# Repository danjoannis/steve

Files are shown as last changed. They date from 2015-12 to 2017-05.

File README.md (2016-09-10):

# steve
Self-Training Electronic Vehicle for Exploration

STEVE is a fun little hobby project, combining an RC tank platform with a Raspberry Pi, Arduino Mega,
and plenty of sensors to allow him to discover the world.

The longterm goal is a robot which can autonomously navigate through environments in order to
reach assigned targets.

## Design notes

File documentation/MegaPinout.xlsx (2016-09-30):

Pin Number | Pin Name | Mapped Pin Name | Peripheral | Function
1 | PG5 ( OC0B ) | Digital pin 4 (PWM)
2 | PE0 ( RXD0/PCINT8 ) | Digital pin 0 (RX0)
3 | PE1 ( TXD0 ) | Digital pin 1 (TX0)
4 | PE2 ( XCK0/AIN0 )
5 | PE3 ( OC3A/AIN1 ) | Digital pin 5 (PWM)
6 | PE4 ( OC3B/INT4 ) | Digital pin 2 (PWM) | MOTOR | EN_A
7 | PE5 ( OC3C/INT5 ) | Digital pin 3 (PWM) | MOTOR | EN_B
8 | PE6 ( T3/INT6 )
9 | PE7 ( CLKO/ICP3/INT7 )
10 | VCC | VCC
11 | GND | GND
12 | PH0 ( RXD2 ) | Digital pin 17 (RX2)
13 | PH1 ( TXD2 ) | Digital pin 16 (TX2)
14 | PH2 ( XCK2 )
15 | PH3 ( OC4A ) | Digital pin 6 (PWM)
16 | PH4 ( OC4B ) | Digital pin 7 (PWM)
17 | PH5 ( OC4C ) | Digital pin 8 (PWM)
18 | PH6 ( OC2B ) | Digital pin 9 (PWM)
19 | PB0 ( SS/PCINT0 ) | Digital pin 53 (SS)
20 | PB1 ( SCK/PCINT1 ) | Digital pin 52 (SCK)
21 | PB2 ( MOSI/PCINT2 ) | Digital pin 51 (MOSI)
22 | PB3 ( MISO/PCINT3 ) | Digital pin 50 (MISO)
23 | PB4 ( OC2A/PCINT4 ) | Digital pin 10 (PWM)
24 | PB5 ( OC1A/PCINT5 ) | Digital pin 11 (PWM)
25 | PB6 ( OC1B/PCINT6 ) | Digital pin 12 (PWM)
26 | PB7 ( OC0A/OC1C/PCINT7 ) | Digital pin 13 (PWM)
27 | PH7 ( T4 )
28 | PG3 ( TOSC2 )
29 | PG4 ( TOSC1 )
30 | RESET | RESET
31 | VCC | VCC
32 | GND | GND
33 | XTAL2 | XTAL2
34 | XTAL1 | XTAL1
35 | PL0 ( ICP4 ) | Digital pin 49
36 | PL1 ( ICP5 ) | Digital pin 48
37 | PL2 ( T5 ) | Digital pin 47
38 | PL3 ( OC5A ) | Digital pin 46 (PWM)
39 | PL4 ( OC5B ) | Digital pin 45 (PWM)
40 | PL5 ( OC5C ) | Digital pin 44 (PWM)
41 | PL6 | Digital pin 43 | SONAR_FRONT | TRIG
42 | PL7 | Digital pin 42 | SONAR_FRONT | ECHO
43 | PD0 ( SCL/INT0 ) | Digital pin 21 (SCL)
44 | PD1 ( SDA/INT1 ) | Digital pin 20 (SDA)
45 | PD2 ( RXDI/INT2 ) | Digital pin 19 (RX1)
46 | PD3 ( TXD1/INT3 ) | Digital pin 18 (TX1)
47 | PD4 ( ICP1 )
48 | PD5 ( XCK1 )
49 | PD6 ( T1 )
50 | PD7 ( T0 ) | Digital pin 38
51 | PG0 ( WR ) | Digital pin 41
52 | PG1 ( RD ) | Digital pin 40
53 | PC0 ( A8 ) | Digital pin 37 | PWR BOARD | MOTOR_EN
54 | PC1 ( A9 ) | Digital pin 36 | PWR BOARD | PI_EN
55 | PC2 ( A10 ) | Digital pin 35
56 | PC3 ( A11 ) | Digital pin 34 | MOTOR | IN_4
57 | PC4 ( A12 ) | Digital pin 33 | MOTOR | IN_3
58 | PC5 ( A13 ) | Digital pin 32 | MOTOR | IN_2
59 | PC6 ( A14 ) | Digital pin 31 | MOTOR | IN_1
60 | PC7 ( A15 ) | Digital pin 30
61 | VCC | VCC
62 | GND | GND
63 | PJ0 ( RXD3/PCINT9 ) | Digital pin 15 (RX3)
64 | PJ1 ( TXD3/PCINT10 ) | Digital pin 14 (TX3)
65 | PJ2 ( XCK3/PCINT11 )
66 | PJ3 ( PCINT12 )
67 | PJ4 ( PCINT13 )
68 | PJ5 ( PCINT14 )
69 | PJ6 ( PCINT 15 )
70 | PG2 ( ALE ) | Digital pin 39
71 | PA7 ( AD7 ) | Digital pin 29
72 | PA6 ( AD6 ) | Digital pin 28
73 | PA5 ( AD5 ) | Digital pin 27
74 | PA4 ( AD4 ) | Digital pin 26
75 | PA3 ( AD3 ) | Digital pin 25
76 | PA2 ( AD2 ) | Digital pin 24
77 | PA1 ( AD1 ) | Digital pin 23
78 | PA0 ( AD0 ) | Digital pin 22
79 | PJ7
80 | VCC | VCC
81 | GND | GND
82 | PK7 ( ADC15/PCINT23 ) | Analog pin 15
83 | PK6 ( ADC14/PCINT22 ) | Analog pin 14
84 | PK5 ( ADC13/PCINT21 ) | Analog pin 13
85 | PK4 ( ADC12/PCINT20 ) | Analog pin 12
86 | PK3 ( ADC11/PCINT19 ) | Analog pin 11
87 | PK2 ( ADC10/PCINT18 ) | Analog pin 10
88 | PK1 ( ADC9/PCINT17 ) | Analog pin 9
89 | PK0 ( ADC8/PCINT16 ) | Analog pin 8
90 | PF7 ( ADC7 ) | Analog pin 7
91 | PF6 ( ADC6 ) | Analog pin 6
92 | PF5 ( ADC5/TMS ) | Analog pin 5
93 | PF4 ( ADC4/TMK ) | Analog pin 4
94 | PF3 ( ADC3 ) | Analog pin 3
95 | PF2 ( ADC2 ) | Analog pin 2
96 | PF1 ( ADC1 ) | Analog pin 1
97 | PF0 ( ADC0 ) | Analog pin 0 | BATTERY | V_batt
98 | AREF | Analog Reference
99 | GND | GND
100 | AVCC | VCC

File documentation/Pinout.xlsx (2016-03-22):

Pin | Digital # | Type | PWM | Special | Assignment
A0 | 14 | Analog
A1 | 15 | Analog
A2 | 16 | Analog
A3 | 17 | Analog
A4 | 18 | Analog |  | SDA | IMU
A5 | 19 | Analog |  | SCL | IMU
PD0 | 0 | Digital |  | RX
PD1 | 1 | Digital |  | TX
PD2 | 2 | Digital |  | INT0
PD3 | 3 | Digital | YES | INT1
PD4 | 4 | Digital
PD5 | 5 | Digital | YES
PD6 | 6 | Digital | YES |  | TRIG
PD7 | 7 | Digital |  |  | ECHO
PB0 | 8 | Digital |  |  | B2
PB1 | 9 | Digital | YES |  | A2
PB2 | 10 | Digital | YES | SS | EN2
PB3 | 11 | Digital | YES | MOSI | EN1
PB4 | 12 | Digital |  | MISO | A1
PB6 | 13 | Digital |  | SCK | B1

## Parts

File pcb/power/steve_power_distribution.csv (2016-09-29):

Id | Designator | Package | Quantity | Designation | Supplier and ref
1 | D1,D2 | SMA_Handsoldering | 2 | D
2 | P1 | TerminalBlock_Pheonix_PT-3.5mm_2pol | 1 | BATT_1
3 | P2 | TerminalBlock_Pheonix_PT-3.5mm_2pol | 1 | BATT_2
4 | P3 | TerminalBlock_Pheonix_PT-3.5mm_2pol | 1 | BATT_3
5 | P4 | TerminalBlock_Pheonix_PT-3.5mm_2pol | 1 | BATT_4
6 | P6 | TerminalBlock_Pheonix_PT-3.5mm_2pol | 1 | MOTORS
7 | P7 | TerminalBlock_Pheonix_PT-3.5mm_2pol | 1 | 5V_PI
8 | P8 | TerminalBlock_Pheonix_PT-3.5mm_2pol | 1 | 5V_AVR
9 | Q1,Q2 | TO-252-2Lead | 2 | Q_NMOS_GDS
10 | R1 | Resistor_Horizontal_RM10mm | 1 | 33k
11 | R2,R5,R6 | Resistor_Horizontal_RM10mm | 3 | 15k
12 | R3,R4 | Resistor_Horizontal_RM10mm | 2 | 220
13 | U1 | LM2596S_CARRIER | 1 | LM2596S_Carrier
14 | P10 | Pin_Header_Straight_1x05 | 1 | AVR_INTERFACE
15 | P9 | TerminalBlock_Pheonix_PT-3.5mm_2pol | 1 | 5V_AUX
16 | P11,P12,P13,P14 | MOUNT_HOLE | 4 | MOUNT_HOLE
17 | P5 | TerminalBlock_Pheonix_PT-3.5mm_2pol | 1 | BATT_AUX

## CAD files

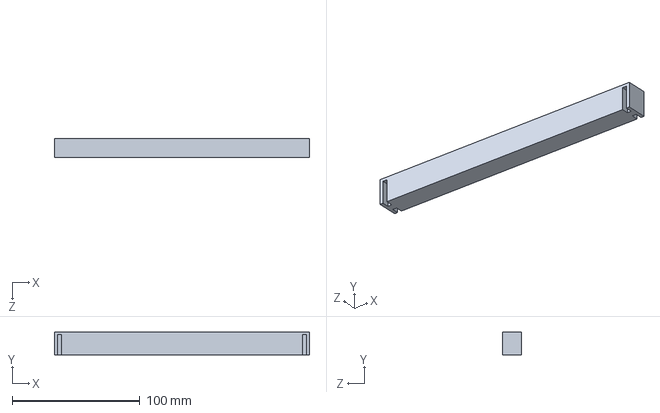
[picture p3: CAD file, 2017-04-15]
3D_Parts/Top_Transverse_Bar.SLDPRT
200.0 x 18.0 x 15.0 mm

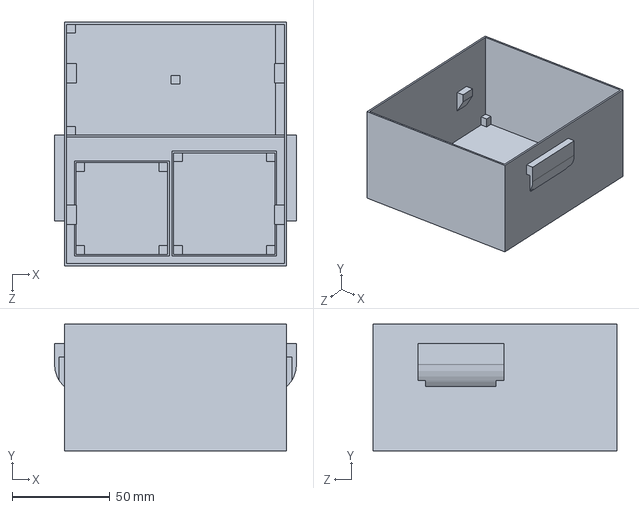
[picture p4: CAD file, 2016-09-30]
3D_Parts/Box_v2.SLDPRT
124.0 x 65.0 x 125.0 mm

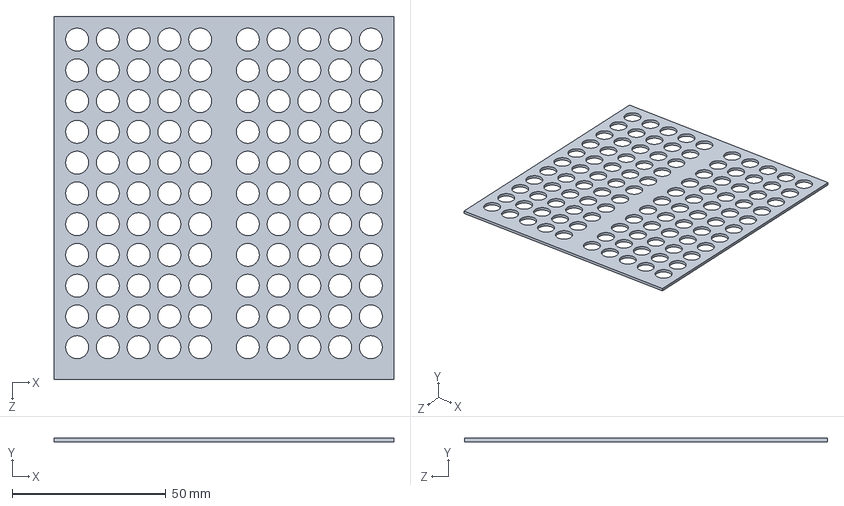
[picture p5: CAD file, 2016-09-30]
3D_Parts/Box_Grill.SLDPRT
110.5 x 1.20 x 118.0 mm

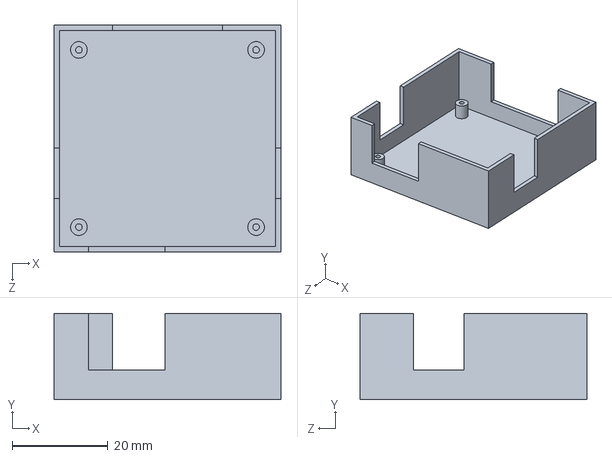
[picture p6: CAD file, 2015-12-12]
3D_Parts/LM298_Box.SLDPRT
47.4 x 18.0 x 47.4 mm

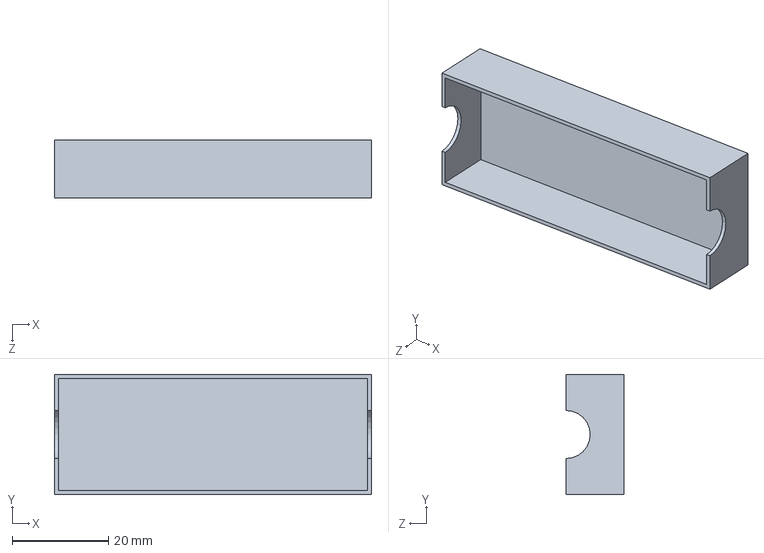
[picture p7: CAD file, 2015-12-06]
3D_Parts/Regulator Box - Top.SLDPRT
66.0 x 25.0 x 12.0 mm

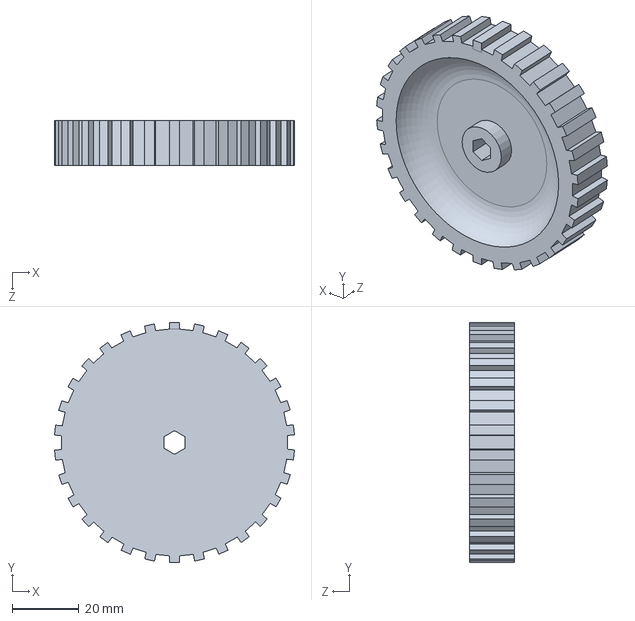
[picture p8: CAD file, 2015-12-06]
3D_Parts/Wheel - Little.SLDPRT
71.9 x 72.0 x 13.4 mm

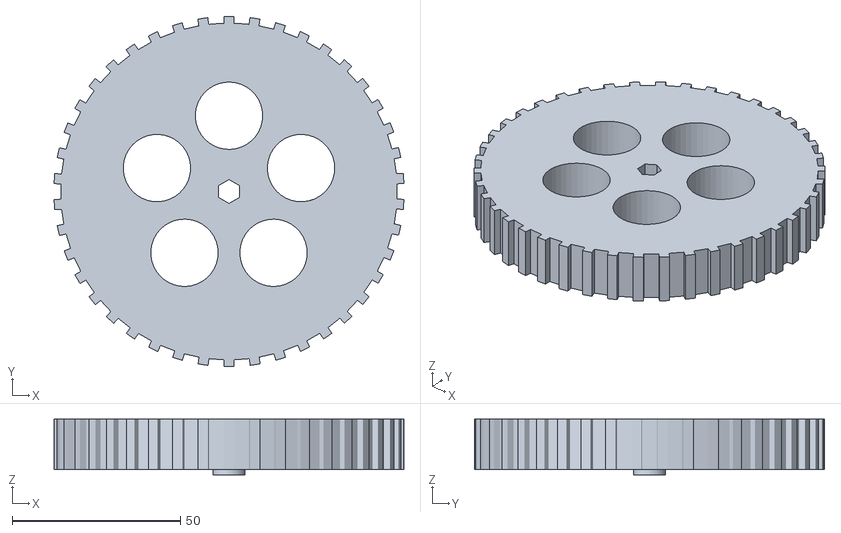
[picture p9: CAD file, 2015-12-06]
3D_Parts/Wheel.STL
103.9 x 104.0 x 16.6

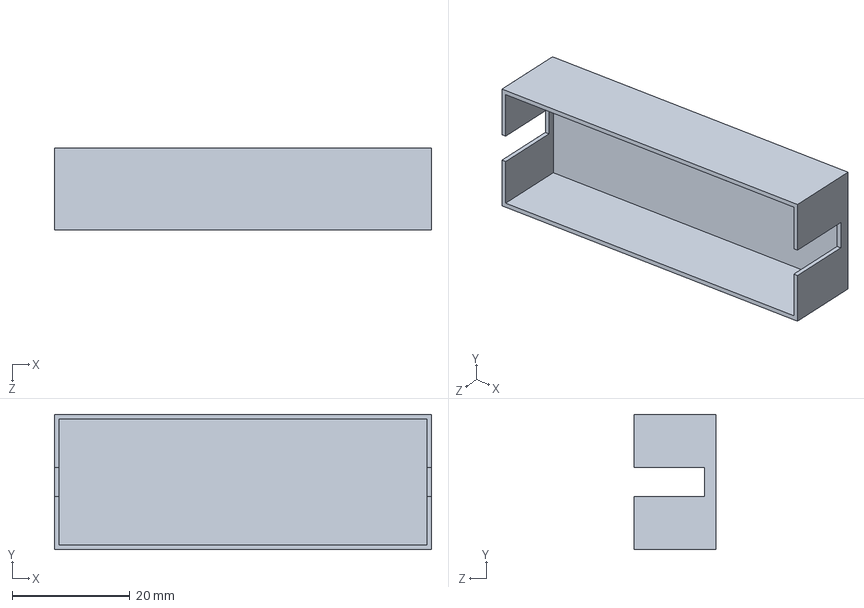
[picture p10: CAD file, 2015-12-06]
3D_Parts/Regulator Box - Bottom.SLDPRT
64.0 x 23.0 x 14.0 mm

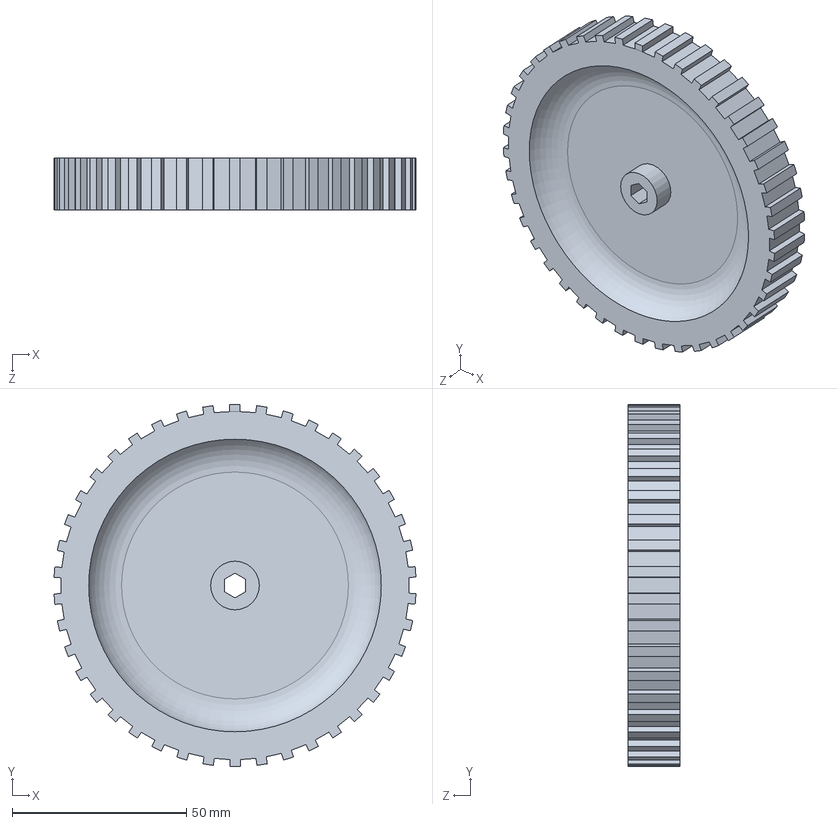
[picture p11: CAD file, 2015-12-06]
3D_Parts/Wheel - Big.SLDPRT
103.9 x 104.0 x 14.8 mm

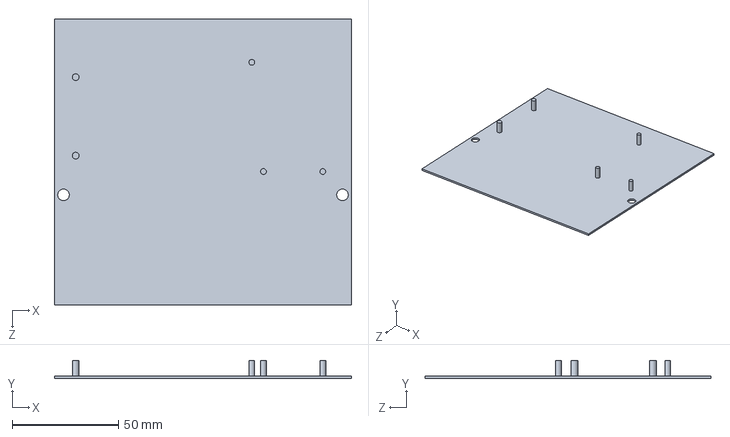
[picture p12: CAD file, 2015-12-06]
3D_Parts/Mounting_Base.SLDPRT
140.0 x 8.70 x 135.0 mm

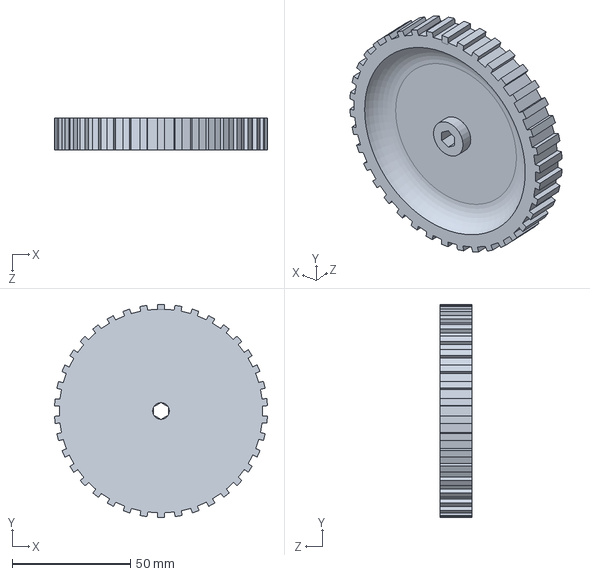
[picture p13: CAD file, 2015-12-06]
3D_Parts/Wheel - Middle.SLDPRT
89.9 x 90.0 x 13.4 mm

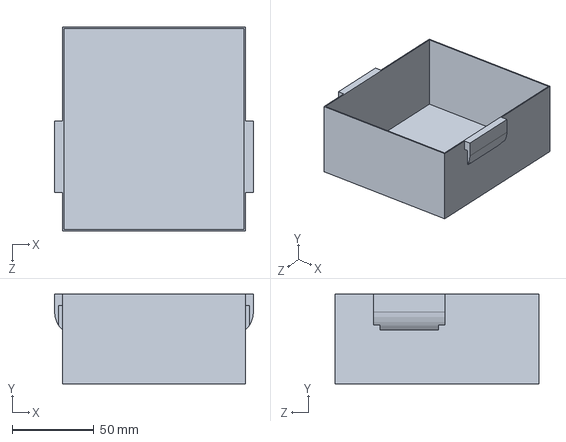
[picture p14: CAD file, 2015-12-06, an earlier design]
3D_Parts/Box.SLDPRT
122.0 x 55.0 x 125.0 mm

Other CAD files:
3D_Parts/Box.STL
3D_Parts/Box_Grill.STL
3D_Parts/Box_v2.STL
3D_Parts/LM298_Box.STL
3D_Parts/Mounting_Base.STL
3D_Parts/Regulator Box - Bottom.STL
3D_Parts/Regulator Box - Top.STL
3D_Parts/Wheel - Big.STL
3D_Parts/Wheel - Little.STL
3D_Parts/Wheel - Middle.STL

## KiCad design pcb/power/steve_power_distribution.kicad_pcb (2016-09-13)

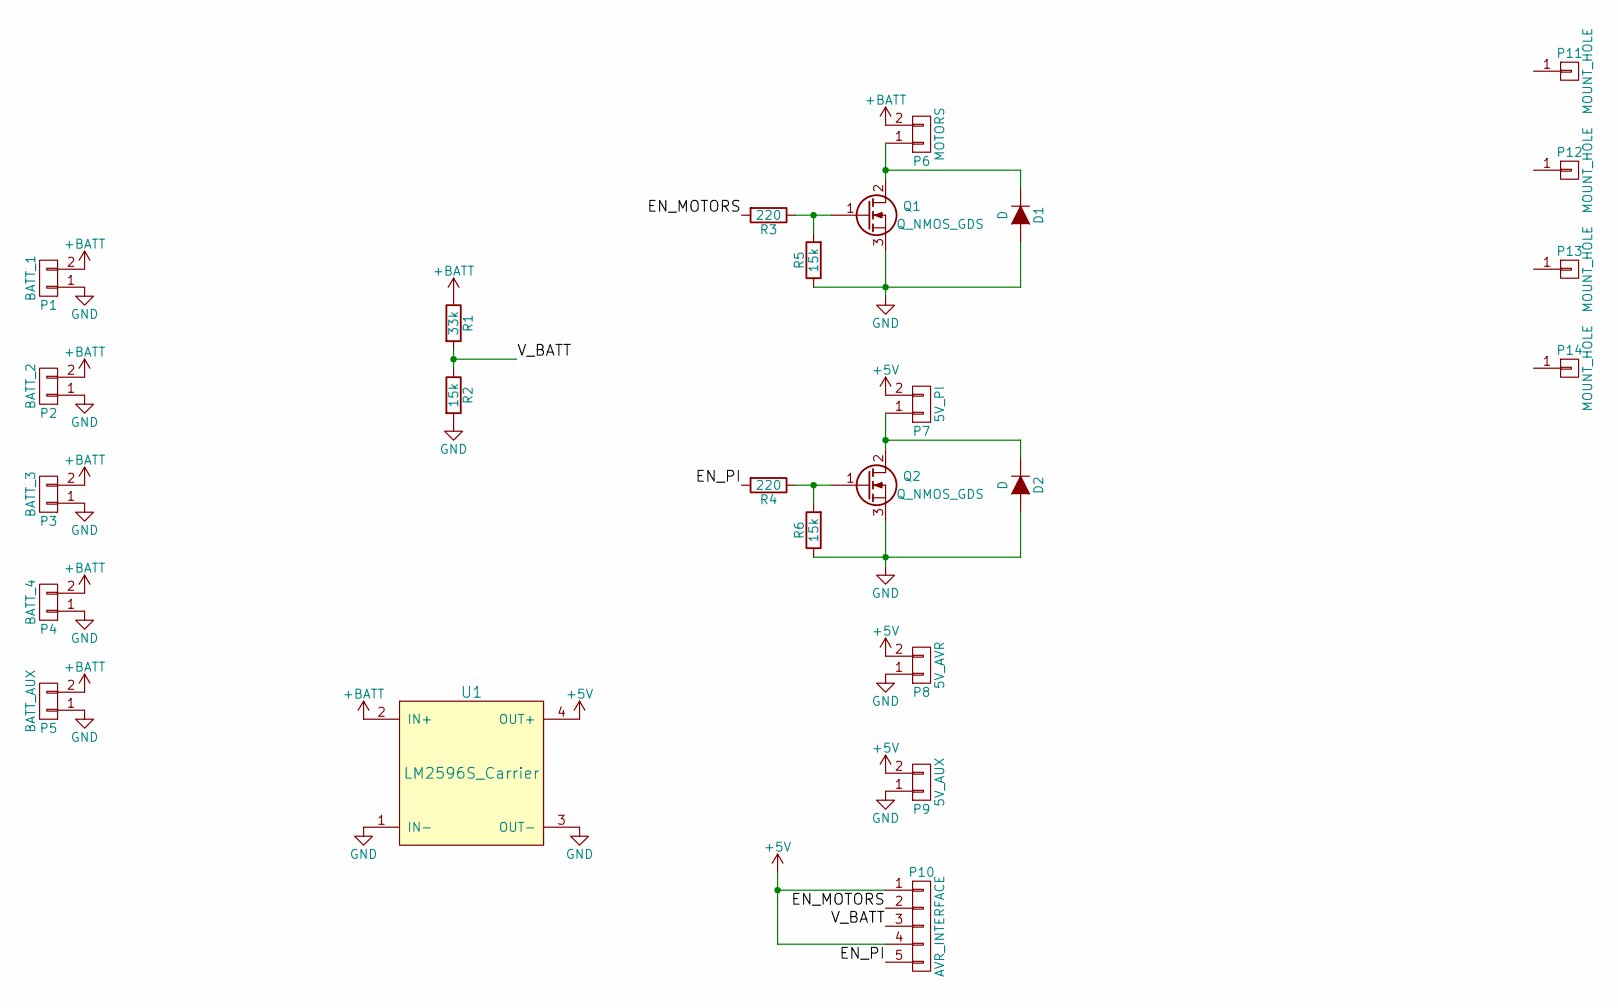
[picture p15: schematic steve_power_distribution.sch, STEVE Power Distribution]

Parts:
D1, D2: D; SMA_Handsoldering
P1: BATT_1; TerminalBlock_Pheonix_PT-3.5mm_2pol
P2: BATT_2; TerminalBlock_Pheonix_PT-3.5mm_2pol
P3: BATT_3; TerminalBlock_Pheonix_PT-3.5mm_2pol
P4: BATT_4; TerminalBlock_Pheonix_PT-3.5mm_2pol
P5: BATT_AUX; TerminalBlock_Pheonix_PT-3.5mm_2pol
P6: MOTORS; TerminalBlock_Pheonix_PT-3.5mm_2pol
P7: 5V_PI; TerminalBlock_Pheonix_PT-3.5mm_2pol
P8: 5V_AVR; TerminalBlock_Pheonix_PT-3.5mm_2pol
P9: 5V_AUX; TerminalBlock_Pheonix_PT-3.5mm_2pol
P10: AVR_INTERFACE; Pin_Header_Straight_1x05
P11, P12, P13, P14: MOUNT_HOLE
Q1, Q2: Q_NMOS_GDS; TO-252-2Lead
R1: 33k; Resistor_Horizontal_RM10mm
R2, R5, R6: 15k; Resistor_Horizontal_RM10mm
R3, R4: 220; Resistor_Horizontal_RM10mm
U1: LM2596S_Carrier; LM2596S_CARRIER

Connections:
+5V: P7.2, P8.2, P9.2, P10.1, P10.4, U1.4 (OUT+)
+BATT: P1.2, P2.2, P3.2, P4.2, P5.2, P6.2, R1.1, U1.2 (IN+)
/EN_MOTORS: P10.2, R3.2
/EN_PI: P10.5, R4.2
/V_BATT: P10.3, R1.2, R2.1
GND: D1.2 (A), D2.2 (A), P1.1, P2.1, P3.1, P4.1, P5.1, P8.1, P9.1, Q1.3 (S), Q2.3 (S), R2.2, R5.1, R6.1, U1.1 (IN-), U1.3 (OUT-)
unnamed: D1.1 (K), P6.1, Q1.2 (D)
unnamed: D2.1 (K), P7.1, Q2.2 (D)
unnamed: Q1.1 (G), R3.1, R5.2
unnamed: Q2.1 (G), R4.1, R6.2

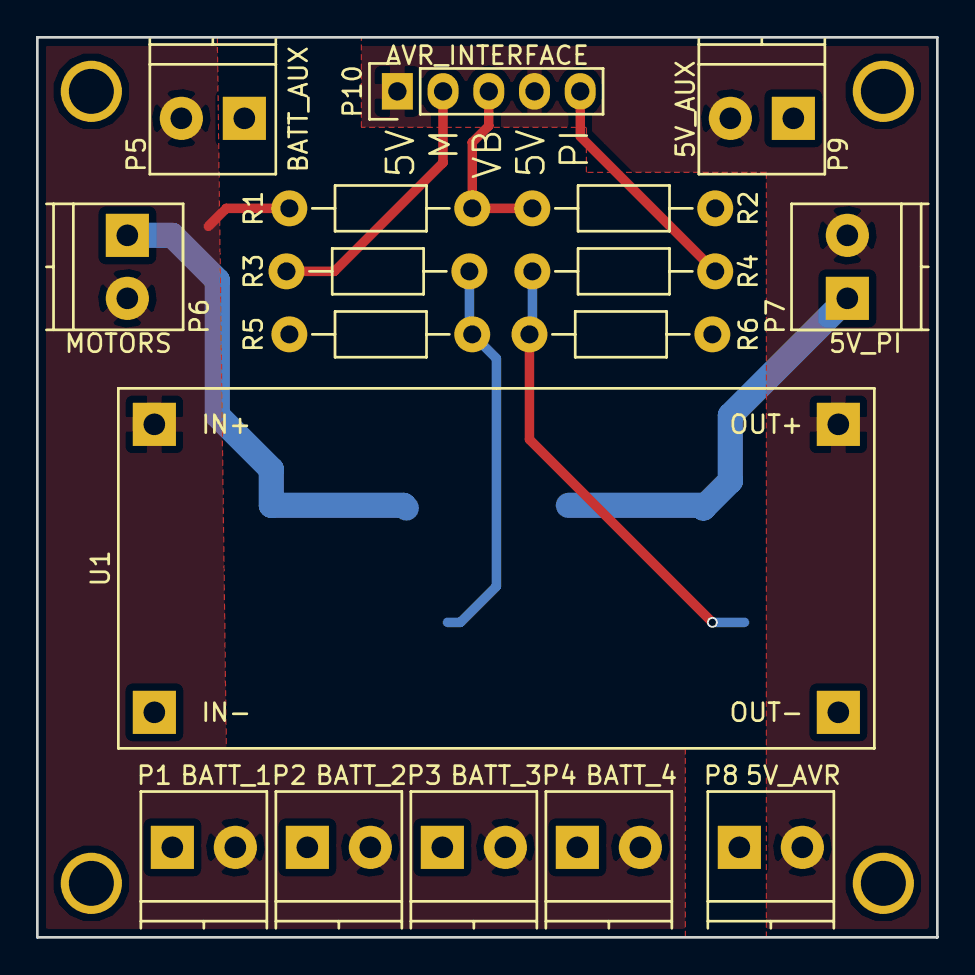
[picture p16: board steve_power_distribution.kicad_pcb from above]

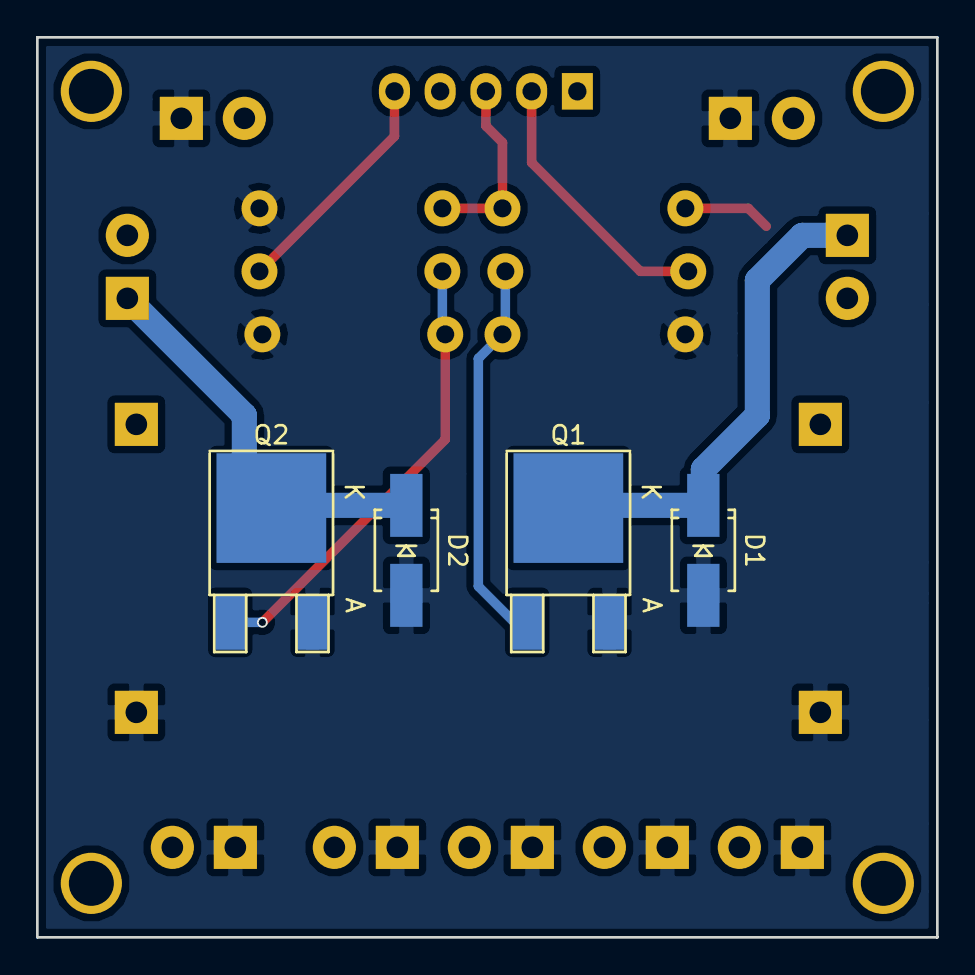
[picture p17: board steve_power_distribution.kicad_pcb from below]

Board: 2 copper layers, 50.0 x 50.0 mm, 25 parts (4 on the bottom side), 10 nets.

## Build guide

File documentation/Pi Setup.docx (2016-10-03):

## Installation procedure for Raspberry Pi

- Prepare a MicroSD card with NOOBS
- Insert into Pi, and boot
- Install Raspbian
- sudo raspi-config
  - Boot to console, not logged in
  - Advanced
    - Audio
      - Force 3.5mm
    - Hostname
- sudo apt-get update
- sudo apt-get install tightvncserver
  - To start it, run tightvncserver :1 -geometry 1280x720 -depth 24
  - To connect, use TightVNC, <ip-address>:5901
- sudo apt-get install git
- sudo apt-get install arduino
- sudo apt-get install python
- sudo apt-get install python-bottle
- sudo apt-get install python-netifaces
- sudo apt-get install flite
- sudo chmod 666 /dev/ttyAMA0
- #sudo apt-get install apache2 libapache2-mod-python
- #sudo usermod -aG dialout www-data
- #sudo a2enmod cgi
- sudo mkdir /steve
  - sudo chown pi:pi /steve
  - cd /
  - git clone https://github.com/danjoannis/steve.git

## Adding WiFi Networks

- sudo nano /etc/interfaces
  - Set DHCP
- sudo nano /etc/wpa_supplicant/wpa_supplicant.conf
- network={ ssid="testing" psk="testingPassword" }
- No spaces (save indenting)

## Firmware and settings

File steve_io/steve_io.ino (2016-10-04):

/*
 * STEVE - Self-Training Electronic Vehicle for Exploration
 * 
 * steve_io : Hardware controller over serial
 * 
 * Allows for the control of STEVE's motors and peripherals,
 * as well as measurement and sampling of various sensors.
 * 
 * Designed for use with Arduino Mega 2560
 * 
 */

// Motors
#define MOTOR_ENA 2  // EN1
#define MOTOR_ENB 3  // EN2
#define MOTOR_A1 31  // IN1
#define MOTOR_A2 32  // IN2
#define MOTOR_B1 33  // IN3
#define MOTOR_B2 34  // IN4

// Power Board
#define MOTOR_PWR_EN 37
#define PI_PWR_EN 36
#define BATT_V_PIN A0

#define NEUTRAL '0'
#define FORWARD '1'
#define REVERSE '2'
#define BRAKE  '3'
#define CENTRE  '0'
#define LEFT  '1'
#define RIGHT   '2'

// Ultrasonic rangefinder
#define US_TRIG 43
#define US_ECHO 42
#define US_TIMEOUT 0xffff
#define US_NO_OBSTACLE 0xfffe

// IMU
#define    MPU9250_ADDRESS            0x68
#define    MAG_ADDRESS                0x0C
 
#define    GYRO_FULL_SCALE_250_DPS    0x00  
#define    GYRO_FULL_SCALE_500_DPS    0x08
#define    GYRO_FULL_SCALE_1000_DPS   0x10
#define    GYRO_FULL_SCALE_2000_DPS   0x18
 
#define    ACC_FULL_SCALE_2_G        0x00  
#define    ACC_FULL_SCALE_4_G        0x08
#define    ACC_FULL_SCALE_8_G        0x10
#define    ACC_FULL_SCALE_16_G       0x18

////////////////////////////////////////////////////////

#include <Wire.h>

////////////////////////////////////////////////////////

volatile unsigned char data_in[8];
volatile unsigned char command_in[8];

volatile unsigned char data_count;
volatile unsigned char command_ready;

////////////////////////////////////////////////////////

void setup() {

  // Initialize communications
  Wire.begin();
  Serial.begin(115200);

  // Initialize pins
  motors_init();
  us_init();
  MPU_init();
  pwr_init();

  // Serial welcome
  Serial.print("Hello. My name is STEVE. \r\n");
}

void loop() {
  if (Serial.available() > 0)
  {
    // Get data from the USART in register
    command_in[data_count] = Serial.read();
  
    // End of line!
    if (command_in[data_count] == '\r')
    {
      command_ready = true;
      // Reset to 0, ready to go again
      data_count = 0;
    }
    else
    {
      data_count++;
    }
  }
  
  if (command_ready == true)
  {
    //copy_command();
    process_command();
    
    command_ready = false;
  }
}

////////////////////////////////////////////////////////

/*
 * Functions
 * 
 * All of the functions are defined below.
 * 
 */

void process_command()
{
  switch (command_in[0])
  {
  case 'P':               // Power command  
    if (command_in[1] == 'M') // Motors
    {
      if (command_in[2] == 'E')
      {
        // Enable motor power
        digitalWrite(MOTOR_PWR_EN, HIGH);
      }
      else if (command_in[2] == 'D')
      {
        // Disable motor power
        digitalWrite(MOTOR_PWR_EN, LOW);
      }
    }
    else if (command_in[1] == 'C') // Computer (RPi)
    {
      if (command_in[2] == 'E')
      {
        // Enable RPi power
        digitalWrite(PI_PWR_EN, HIGH);
      }
      else if (command_in[2] == 'D')
      {
        // Disable RPi power
        digitalWrite(PI_PWR_EN, LOW);
      }      
    }
    break;
  case 'D':               // Drive command
    if (command_in[1] == '=')
    {
      // Drive command
      motors_go_tank(command_in[2], command_in[3], command_in[4]);
    }
    else if (command_in[1] == 'S')
    {
      // Stop command
      motors_stop_tank();
    }
    break;
  case 'Q':               // Query command
    if (command_in[1] == '?')
    {
      if (command_in[2] == 'U')   // Ultrasonic range finder
      {
        uint16_t result = us_measure();
        Serial.print(String(result/58));
        Serial.print("\r\n");
      }
      else if (command_in[2] == 'M')  // Magnetometer
      {
        MPU_read(); 
      }
      else if (command_in[2] == 'B')  // Battery
      {
        Serial.print(String(get_battery_voltage()));
        Serial.print("\r\n");
      }
    }
    break;
  case 'A':               // Sample command
    if (command_in[1] == '?')
    {
      // Do the query action for R
      Serial.print("Name .:. A=\r\n");
    }
    else if (command_in[1] == '=')
    {
      // Do the set action for A
    }
    break;
  default:
    Serial.print("CMD Error\r\n");
    break;
  }
}

void us_init()
{
  pinMode(US_TRIG, OUTPUT);
  pinMode(US_ECHO, INPUT);
}

uint16_t us_measure()
{
  uint32_t i,result;

  //Send the trigger
  digitalWrite(US_TRIG, HIGH);
  delayMicroseconds(15);
  digitalWrite(US_TRIG, LOW);
  delayMicroseconds(20);

  //Wait for the rising edge
  for(i=0;i<600000;i++)
  {
    if(!digitalRead(US_ECHO)) continue; else break;
  }

  if(i==600000)
    return US_TIMEOUT;  //Indicates time out

  //High Edge Found

  //Setup Timer1
  TCCR1A=0X00;
  TCCR1B=(1<<CS11); //Prescaler = Fcpu/8
  TCNT1=0x00;     //Init counter

  //Now wait for the falling edge
  for(i=0;i<600000;i++)
  {
    if(digitalRead(US_ECHO))
    {
      if(TCNT1 > 60000) break; else continue;
    }
    else
      break;
  }

  if(i==600000)
    return US_TIMEOUT;  //Indicates time out

  //Falling edge found

  result=TCNT1;

  //Stop Timer
  TCCR1B=0x00;

  if(result > 60000)
    return US_NO_OBSTACLE;  //No obstacle
  else
    return (result>>1);
}

float get_battery_voltage()
{
  return (16 * (float)analogRead(BATT_V_PIN) / 1023);
}

void pwr_init()
{
  // Configure outputs
  pinMode(MOTOR_PWR_EN, OUTPUT);
  pinMode(PI_PWR_EN, OUTPUT);

  // Default OFF
  digitalWrite(MOTOR_PWR_EN, LOW);
  digitalWrite(PI_PWR_EN, LOW);

  // If cell voltage is high enough, enable Raspberry Pi
  if(get_battery_voltage() > 6.6)
  {
    digitalWrite(PI_PWR_EN, HIGH);
  }
}

void motors_init()
{
  // Configure outputs
  pinMode(MOTOR_ENA, OUTPUT);
  pinMode(MOTOR_ENB, OUTPUT);
  pinMode(MOTOR_A1, OUTPUT);
  pinMode(MOTOR_A2, OUTPUT);
  pinMode(MOTOR_B1, OUTPUT);
  pinMode(MOTOR_B2, OUTPUT);

  // Stop all motors
  motors_stop_tank();
}

void motors_go_tank(byte direction, byte heading, byte duty)
{
  //Forward: MOTOR_X1 = HIGH, MOTOR_X2 = LOW
  //Reverse: MOTOR_X1 = LOW, MOTOR_X2 = HIGH
  //Brake: MOTOR_X1 = MOTOR_X2

  // Reset motors to off
  motors_stop_tank();
  
  byte duty_left;
  byte duty_right;
  byte duty_forward;
  
  if (duty == '0') duty = 0;
  else if (duty == '1') duty_forward = 180;
  else if (duty == '2') duty_forward = 190;
  else if (duty == '3') duty_forward = 200;
  else if (duty == '4') duty_forward = 225;
  else if (duty == '5') duty_forward = 255;
  
  /* Lowest usable duty is 200, so proportion in %
  if ((duty < 1) | (duty > 5)) duty_forward = 0;
  else duty_forward = 150 + (105 * duty / 5);
  */
  
  if (heading == CENTRE)
  {
    duty_left = duty_forward;
    duty_right = duty_forward;
  }
  else if (heading == LEFT)
  {
    duty_left = 0;
  }
  else if (heading == RIGHT)
  {
    duty_right = 0;
  }
  
  if (direction == FORWARD)
  {
    digitalWrite(MOTOR_A1, HIGH);
    digitalWrite(MOTOR_B1, HIGH);
  }
  else if (direction == REVERSE)
  {    
    digitalWrite(MOTOR_A2, HIGH);
    digitalWrite(MOTOR_B2, HIGH);
  }
  else if (direction == NEUTRAL)
  {
    // No forward, only pivot
    if (heading == LEFT)
    {
      digitalWrite(MOTOR_A2, HIGH);
      digitalWrite(MOTOR_B1, HIGH);
      duty_left = duty_forward;
      duty_right = duty_forward;
    }
    else if (heading == RIGHT)
    {
      digitalWrite(MOTOR_A1, HIGH);
      digitalWrite(MOTOR_B2, HIGH);
      duty_left = duty_forward;
      duty_right = duty_forward;
    }
  }
  else if (direction == BRAKE)
  {     
    /* Doesn't really have a purpose right now   
    digitalWrite(MOTOR_A1, HIGH);
    digitalWrite(MOTOR_A2, HIGH);
    digitalWrite(MOTOR_B1, HIGH);
    digitalWrite(MOTOR_B2, HIGH);
    */
  }

  analogWrite(MOTOR_ENA, duty_left);
  analogWrite(MOTOR_ENB, duty_right);
}

void motors_stop_tank()
{
  // Set all low
  digitalWrite(MOTOR_ENA, LOW);
  digitalWrite(MOTOR_ENB, LOW);
  digitalWrite(MOTOR_A1, LOW);
  digitalWrite(MOTOR_A2, LOW);
  digitalWrite(MOTOR_B1, LOW);
  digitalWrite(MOTOR_B2, LOW);
}

// This function read Nbytes bytes from I2C device at address Address. 
// Put read bytes starting at register Register in the Data array. 
void I2Cread(uint8_t Address, uint8_t Register, uint8_t Nbytes, uint8_t* Data)
{
  // Set register address
  Wire.beginTransmission(Address);
  Wire.write(Register);
  Wire.endTransmission();
 
  // Read Nbytes
  Wire.requestFrom(Address, Nbytes); 
  uint8_t index=0;
  while (Wire.available())
    Data[index++]=Wire.read();
}
 
// Write a byte (Data) in device (Address) at register (Register)
void I2CwriteByte(uint8_t Address, uint8_t Register, uint8_t Data)
{
  // Set register address
  Wire.beginTransmission(Address);
  Wire.write(Register);
  Wire.write(Data);
  Wire.endTransmission();
}

void MPU_init()
{
  // Configure gyroscope range
  I2CwriteByte(MPU9250_ADDRESS,27,GYRO_FULL_SCALE_2000_DPS);
  // Configure accelerometers range
  I2CwriteByte(MPU9250_ADDRESS,28,ACC_FULL_SCALE_16_G);
  // Set by pass mode for the magnetometers
  I2CwriteByte(MPU9250_ADDRESS,0x37,0x02);
 
  // Request first magnetometer single measurement
  I2CwriteByte(MAG_ADDRESS,0x0A,0x01);
}

void MPU_read()
{
  // Read accelerometer and gyroscope
  uint8_t Buf[14];
  I2Cread(MPU9250_ADDRESS,0x3B,14,Buf);
 
  // Create 16 bits values from 8 bits data
  // Accelerometer
  int16_t ax=-(Buf[0]<<8 | Buf[1]);
  int16_t ay=-(Buf[2]<<8 | Buf[3]);
  int16_t az=Buf[4]<<8 | Buf[5];
 
  // Gyroscope
  int16_t gx=-(Buf[8]<<8 | Buf[9]);
  int16_t gy=-(Buf[10]<<8 | Buf[11]);
  int16_t gz=Buf[12]<<8 | Buf[13];
 
  // Display values 
  // Accelerometer
  Serial.print (ax,DEC); 
  Serial.print ("\t");
  Serial.print (ay,DEC);
  Serial.print ("\t");
  Serial.print (az,DEC);  
  Serial.print ("\t");
 
  // Gyroscope
  Serial.print (gx,DEC); 
  Serial.print ("\t");
  Serial.print (gy,DEC);
  Serial.print ("\t");
  Serial.print (gz,DEC);  
  Serial.print ("\t");

  // :::  Magnetometer ::: 
  // Read register Status 1 and wait for the DRDY: Data Ready
  uint8_t ST1;
  do
  {
    I2Cread(MAG_ADDRESS,0x02,1,&ST1);
  }
  while (!(ST1&0x01));
 
  // Read magnetometer data  
  uint8_t Mag[7];  
  I2Cread(MAG_ADDRESS,0x03,7,Mag);
  
  // Create 16 bits values from 8 bits data
  // Magnetometer
  int16_t mx=-(Mag[3]<<8 | Mag[2]);
  int16_t my=-(Mag[1]<<8 | Mag[0]);
  int16_t mz=-(Mag[5]<<8 | Mag[4]);
  
  // Magnetometer
  Serial.print (mx+200,DEC); 
  Serial.print ("\t");
  Serial.print (my-70,DEC);
  Serial.print ("\t");
  Serial.print (mz-700,DEC);  
  Serial.print ("\t");
  
  // End of line
  Serial.print("\r\n");
         
  MPU_init();
}

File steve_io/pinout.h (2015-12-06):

/*
 * pinout.h
 *
 *  Created on: Nov 1, 2015
 *      Author: Daniel
 */

#ifndef PINOUT_H_
#define PINOUT_H_

// Motor controller
#define MOTOR_DDR DDRD
#define MOTOR_PORT PORTD
#define MOTOR_EN1 0
#define MOTOR_EN2 1
#define MOTOR_A1 2
#define MOTOR_B1 3
#define MOTOR_A2 4
#define MOTOR_B2 5

// Ultrasonic rangefinder
#define US_DDR DDRD
#define US_PORT PORTD
#define US_PIN PIND
#define US_TRIG 6
#define US_ECHO 7

#endif /* PINOUT_H_ */

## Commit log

2015-12-06 Real initial commit
    Initial commit of all source code, 3D files, and documentation developed
    to date.
    [Box.SLDPRT, Box.STL, Mounting_Base.SLDPRT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]
2015-12-06 First python bits for connecting with Arduino
2015-12-12 Created 3d model for LM298 holder
    [LM298_Box.SLDPRT, LM298_Box.STL]
2015-12-12 Modified serial library for arduino
2015-12-13 Fixes to allow compiling, due to printf
2016-03-20 Moved to Arduino platform
    Library support for AVR is pretty sad; switched it all to Arduino for
    better PWM and etc support.
    Renamed old code to arduino_io_legacy
2016-03-21 Updated motor dynamics (again); need to change pin assignment.
2016-03-22 Added pinout document
    [Pinout.xlsx]
2016-03-22 Actually fixed motor pinout and stuff
    [steve_io.ino]
2016-03-22 Updated pinout document
    [Pinout.xlsx]
2016-09-10 Added new pinout document for Mega
    [MegaPinout.xlsx]
2016-09-11 Initial PCB schematic capture and KiCAD project
    [steve_power_distribution.kicad_pcb, steve_power_distribution.sch]
2016-09-11 Added serial interface to web server, fixed baud rate
    [steve_web.py]
2016-09-12 Semi finalized PCB layout
    [steve_power_distribution.sch]
2016-09-12 Missing semi colon, missing quotes
    [steve_web.py]
2016-09-13 Finalized PCB design and generated gerbers for manufacture
    [steve_power_distribution.kicad_pcb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]
2016-09-14 Added error handling for serial connection and Steve voice
    [steve_web.py]
2016-09-14 Fixed process running maybe
    [steve_web.py]
2016-09-29 New box 3d part
    [Box_v2.SLDPRT, Box_v2.STL]
2016-09-29 Updated pinout and BOM for PCB
    [MegaPinout.xlsx, steve_power_distribution.csv]
2016-09-30 Updated electronics box, added grill, updated pinout, added code for power board
    [Box_Grill.SLDPRT, Box_Grill.STL, Box_v2.SLDPRT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]
2016-10-03 Updated web interface and python script for stability; disabled warehouse; added remote IP setting
    [steve_web.py]
2016-10-03 Improved battery voltage function
2016-10-04 Improved (maybe) motor controls, added power management functions
2016-10-04 Added IP watchdog process and a poweroff method
2017-04-15 New 3D model for widening body
    [Top_Transverse_Bar.SLDPRT]
